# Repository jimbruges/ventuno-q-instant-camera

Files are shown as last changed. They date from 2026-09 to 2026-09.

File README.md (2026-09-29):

# VENTUNO Q Instant Camera

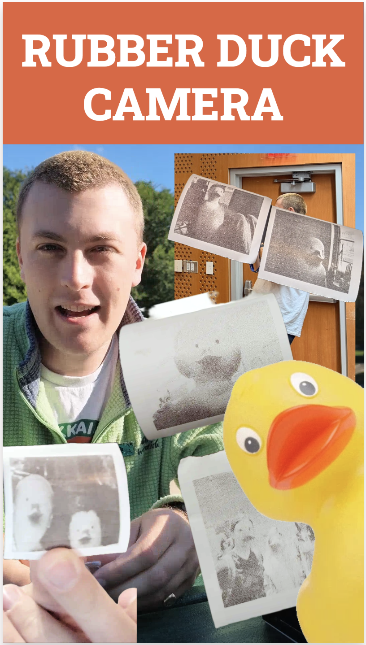
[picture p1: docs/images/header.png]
VENTUNO Q Rubber Duck Camera


A headless instant-camera photobooth for the Arduino VENTUNO Q. It combines a USB webcam, Modulino Buttons and Pixels, the onboard LED matrix, a serial thermal printer, local VLM descriptions, and optional local NPU or cloud image editing.

> [Watch the build video on YouTube](https://www.youtube.com/shorts/uCNsJqf2ZmI)

## Start here

1. Read the [hardware build guide](hardware/README.md) to print the case, assemble the camera, and wire the printer safely.
2. Run [`./install.sh`](#install-on-a-ventuno-q) on a VENTUNO Q to install the application and optional local image-editing bundle.
3. Open the browser interface at `http://<board-ip>:7000` to configure the button profiles and make a test print.

The camera can run completely headless once it has been configured. Use the three Modulino Buttons as the shutter controls, while the Modulino Pixels and the VENTUNO Q LED matrix provide flash and status feedback.

## What it does

| Mode | Result |
| --- | --- |
| Normal | Captures the webcam image and prints it as a 384-dot monochrome receipt. |
| Local | Uses the VENTUNO Q NPU to edit the image locally. The default prompt replaces people's heads with rubber ducks. |
| Cloud | Sends an image-edit request through OpenRouter; this mode requires an API key and network access. |
| Describe | Uses the built-in local VLM to describe the scene and prints the text instead of a photo. |

- Six independently configurable profiles: a short press and a long press for each of the three buttons.
- A browser UI on port 7000 for configuration, live previews, test prints, and recent-print history.
- Screenless Android Wi-Fi setup by scanning a Wi-Fi sharing QR code with the webcam.
- Local image editing through QNN/HTP contexts compiled for the VENTUNO Q QCS8275.

## Hardware

- Arduino VENTUNO Q with a current App Lab image and `arduino-app-cli`.
- UVC USB webcam.
- Modulino Buttons and Modulino Pixels connected over Qwiic/I2C.
- TTL thermal printer on D1/TX at 9600 baud, powered by the dedicated 9 V output of the USB-C PD trigger and sharing ground with the VENTUNO Q.

See the [hardware build guide](hardware/README.md) for assembly and wiring, and [the app README](ArduinoApps/instant-me-camera/README.md) for controls and operation.

### Bill of materials

| Component | Quantity |
| --- | ---: |
| [USB C PD 9V trigger adapter](https://m.media-amazon.com/images/I/71KljqwlDBL._AC_SX679_.jpg) | 1 |
| USB-C panel-mount extension cable | 1 |
| Anker USB-C power bank | 1 |
| [Modulino Buttons](https://cdn.shopify.com/s/files/1/0438/4735/2471/files/ABX00110_01.iso.jpg?v=1747144627) | 1 |
| [Snap-in spacers for Modulino boards and VENTUNO Q](https://media.rs-online.com/image/upload/bo_1.5px_solid_white,b_auto,c_pad,dpr_2,f_auto,h_399,q_auto,w_710/c_pad,h_399,w_710/F0304193-01?pgw=1) | 14 |
| [CSN-A2 58mm thermal printer](https://thepihut.com/cdn/shop/files/mini-thermal-receipt-printer-the-pi-hut-105116-40741308137667_1000x.jpg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) | 1 |
| [Modulino Pixels](https://cdn.shopify.com/s/files/1/0438/4735/2471/files/ABX00109_01.iso.jpg?v=1747144631) | 1 |
| M3 x 5 mm heat-set inserts | 4 |
| [Logitech C270 webcam](https://m.media-amazon.com/images/I/61yo4swj-PL._AC_SX679_.jpg) | 1 |
| [40 colored male-to-male jumper wires](https://cdn.shopify.com/s/files/1/0438/4735/2471/files/TPX00160_00.default_6a832518-bf2a-406c-a2d1-a554b9949905.jpg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) | 1 pack |
| 15 cm solid-core hookup wires | 2 |
| [Arduino VENTUNO Q](https://cdn.shopify.com/s/files/1/0438/4735/2471/files/ABX00181_01.iso.jpg?v=1784300672) | 1 |
| M3 x 5 mm caphead screws | 4 |
| [Qwiic cable bundle](https://cdn.shopify.com/s/files/1/0438/4735/2471/files/TPX00232_01.iso.jpg?v=1755589661) | 1 bundle |

## 3D-printed enclosure

The enclosure is a three-part print sized around the VENTUNO Q, webcam, thermal printer, and Modulino boards: a top shell with the carry handle and camera/button cutouts, a bottom shell with a printer bay, and a vented side panel for airflow around the board.

| Front cutouts | Vented side panel | Interior shell |
| --- | --- | --- |
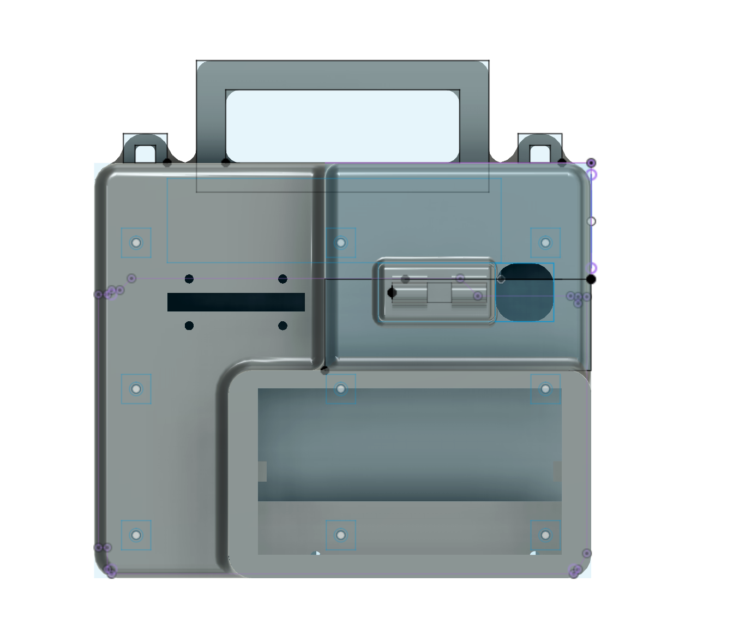
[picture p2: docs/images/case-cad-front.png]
Front panel with lens, button, and printer cutouts
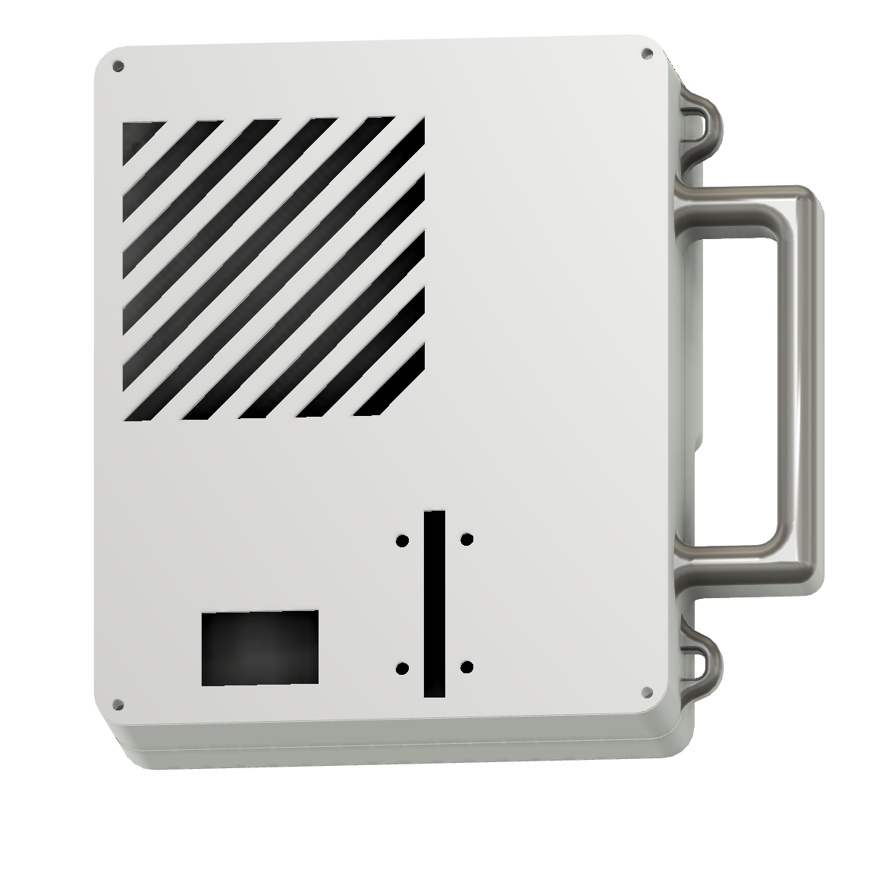
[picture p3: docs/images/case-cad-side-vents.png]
Side panel with ventilation slots and carry handle
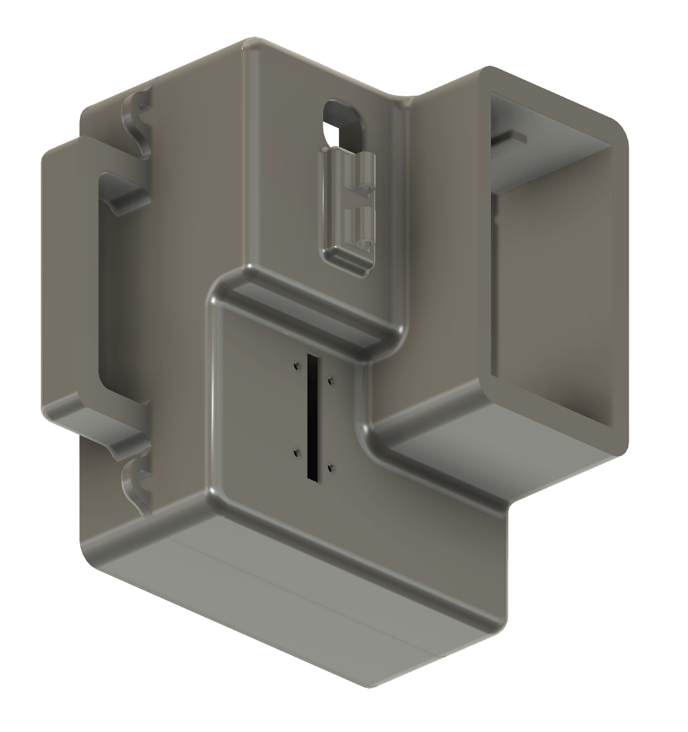
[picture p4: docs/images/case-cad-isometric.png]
Interior view of the printed shell
|  |  |  |

Use this layout for printing; supports are required for the front plate:

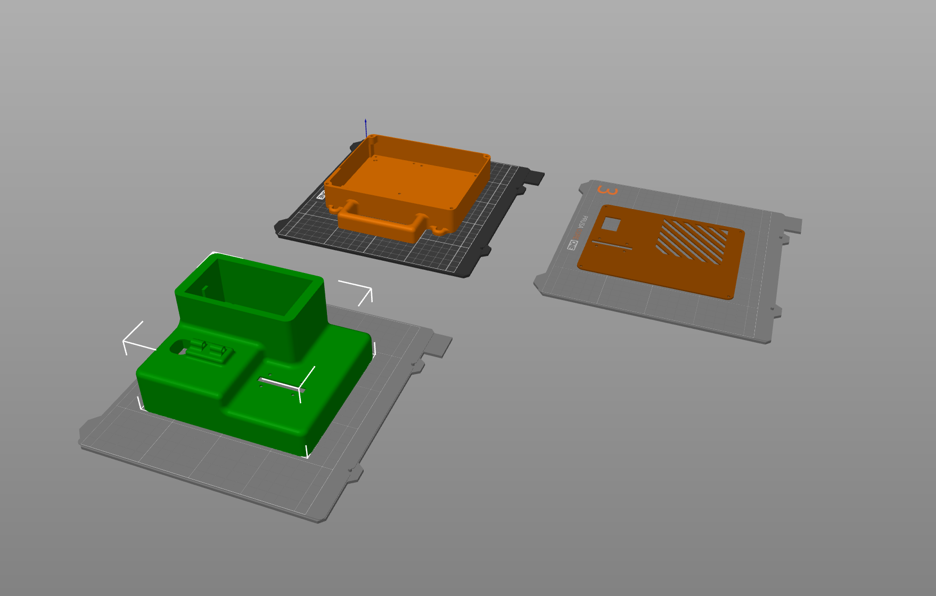
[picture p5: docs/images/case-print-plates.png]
Slicer plate layout for the lid, body, and side panel


Download the [3MF enclosure file](hardware/ventuno-q-instant-camera.3mf) for all three parts. See the [hardware build guide](hardware/README.md) for the assembly sequence.

Tested on a Prusa Core One+.

## Install on a VENTUNO Q

The installer is intended to run on the VENTUNO Q. It downloads about 3.1 GB of
compressed NPU runtime/model artifacts from Hugging Face, installs roughly 6 GB,
and needs at least 8 GB free during installation. Model downloads are public and
do not require a Hugging Face account.

```bash
git clone https://github.com/jimbruges/ventuno-q-instant-camera.git
cd ventuno-q-instant-camera
./install.sh
```

The installer:

1. Verifies that it is running on a VENTUNO Q.
2. Copies the Arduino App to `~/ArduinoApps/instant-me-camera`.
3. Downloads and checksum-verifies the pinned Hugging Face `v1` model bundle.
4. Installs the portable NPU and Wi-Fi user services.
5. Enables both services, sets the app as the boot default, and starts it.

Then open `http://<board-ip>:7000`. The first NPU startup may take up to two minutes.

Useful alternatives:

```bash
./install.sh --skip-models   # Normal, Cloud, and Describe modes only
./install.sh --no-start      # Install without starting or changing the default app
./scripts/install-models.sh  # Install/reinstall only the local NPU bundle
```

The installer preserves runtime `config.json`, `.secrets.json`, captures, and profile photos on upgrades.

> **Want the fastest first print?** Run `./install.sh --skip-models` to install Normal, Cloud, and Describe modes without the multi-gigabyte local editor. You can add Local mode later with `./scripts/install-models.sh`.

## Configuration

The app works without `config.json`; defaults are portable and discover the Docker host gateway automatically. To customize settings manually:

```bash
cp ~/ArduinoApps/instant-me-camera/config.example.json \
   ~/ArduinoApps/instant-me-camera/config.json
```

Cloud mode needs an OpenRouter API key entered in the Web UI. It is stored in the ignored, owner-only `.secrets.json` file and is never committed.

## Models and large files

Model files are not stored in Git history. The supported bundle is distributed
as checksummed artifacts from a dedicated Hugging Face model repository. This
keeps source clones small while pinning the exact ARM64 runtime and QCS8275
contexts.

See [MODELS.md](MODELS.md) for artifact contents, upstream model licenses, and installation details.

## License

Original source code, documentation, and enclosure CAD files in this repository
are available under the [Mozilla Public License 2.0](LICENSE), unless a file or
directory includes a different notice. Third-party libraries, model artifacts,
reference images, product images linked from the bill of materials, Arduino and
Qualcomm components, and the trademarks shown in this project remain subject to
their respective licenses and terms. See [MODELS.md](MODELS.md) and
[huggingface/README.md](huggingface/README.md) for the local model licensing and
provenance details.

## Repository layout

- `ArduinoApps/instant-me-camera/`: App Lab application, MCU sketch, Web UI, and Wi-Fi helper.
- `instant-camera-ai/src/`: local QNN inference pipeline.
- `instant-camera-ai/bin/start-npu-router`: portable NPU service launcher.
- `instant-camera-ai/systemd/`: user service template.
- `scripts/install-models.sh`: release artifact downloader and verifier.
- `install.sh`: complete board installer.
- `hardware/`: 3D-printable enclosure source (`.3mf`) and build instructions.
- `docs/images/`: README screenshots and renders.

## Operations

```bash
systemctl --user status instant-camera-npu.service
systemctl --user status instant-camera-wifi.service
curl http://127.0.0.1:7100/health
arduino-app-cli app logs ~/ArduinoApps/instant-me-camera --tail 100
arduino-app-cli app start ~/ArduinoApps/instant-me-camera
```

Only one Arduino App can run at a time. Starting this app stops the currently running app.

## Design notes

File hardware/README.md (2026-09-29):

# Hardware build

This folder contains the [VENTUNO Q Instant Camera enclosure](ventuno-q-instant-camera.3mf). The enclosure is a three-part print for the VENTUNO Q, Logitech C270 webcam, CSN-A2 58 mm thermal printer, Modulino Buttons, and Modulino Pixels.

## Parts

- Arduino VENTUNO Q
- Logitech C270
- Modulino Buttons
- Modulino Pixels
- Snap-in spacers for Modulino boards and VENTUNO Q, 14
- CSN-A2 58 mm thermal printer
- USB-C PD 9 V trigger adapter and a compatible USB-C PD power source
- USB-C panel-mount extension cable, 1
- Anker USB-C power bank, 1
- Qwiic cables for the Modulino peripherals
- M3 x 5 mm heat-set inserts, 4
- M3 x 5 mm caphead screws, 4
- 15 cm solid-core hookup wires, 2
- Male-to-male jumper wires for the printer serial connection and other signal connections

The complete bill of materials, including product references, is in the [main README](../README.md#bill-of-materials).

## Print the enclosure

1. Open `ventuno-q-instant-camera.3mf` in the slicer.
2. Keep the three enclosure parts on their intended plates and confirm the printer profile matches the selected material.
3. Use supports for the front plate. Check the camera mount, button, and printer openings after slicing.
4. Print the parts and remove support material before installing electronics.
5. Test-fit the VENTUNO Q, printer, webcam, and Modulino parts before tightening the enclosure screws.

The model was tested on a Prusa Core One+. The `.3mf` contains the printable enclosure source; it does not include the electronics or fasteners.

## Install the heat-set inserts

Install four M3 x 5 mm inserts in the enclosure's prepared mounting holes:

1. Heat a soldering iron to the insert manufacturer's recommended temperature.
2. Place each insert squarely over its printed hole.
3. Press it in slowly until it is flush with the plastic surface. Do not force it below the mounting surface.
4. Let the plastic cool completely, then test each thread with an M3 screw.

Keep the insert aligned while it is hot. Misaligned inserts can prevent the shells from closing or damage the printed mounting bosses.

## Mount the components

Before committing the electronics to the enclosure, connect the VENTUNO Q, Modulino boards, thermal printer, and camera on the bench and confirm that the App starts and the camera is visible.

### Front plate

1. Remove the C270 factory mounting clip by popping off the hinge end cap and removing the screw. Reattach the clip to the front plate; its keyed shaft fits in one direction. Feed the USB cable through the enclosure opening before securing the camera.
2. Feed the printer cables through the printer opening. Use double-sided tape on the printer body to hold the printer in position, keeping the paper path aligned with the front slot.
3. Fit the snap-in spacers and attach the Modulino Pixels to the front plate. Feed a long Qwiic cable through from the Pixels board.
4. Set the USB-C PD screw-terminal adapter to its switched 9 V mode. Connect its output to the printer power terminals, then add the two 15 cm solid-core wires for the VENTUNO Q power input.
5. Secure the panel-mount USB-C extension in the enclosure and connect its internal end to the USB-C PD screw-terminal adapter.

### Middle and rear panels

1. Feed all loose cables through the panel gap before fastening the middle mounting panel to the front plate.
2. Connect the printer RX input to VENTUNO Q D1 / TX with a jumper wire. The current sketch only sends print data; leave printer TX disconnected unless it is level-shifted to 3.3 V before connecting to D0 / RX.
3. Connect the USB camera and route its cable clear of the printer and paper path.
4. Connect the two printer power leads to the VENTUNO Q screw terminals marked 5-24 V and GND. The printer and VENTUNO Q must share ground.
5. Fit the snap-in spacers for the Modulino Buttons on the outer side of the rear panel and attach the board.
6. Test-fit the VENTUNO Q in its opening before pressing in its snap-in spacers. The fit can be tight; confirm alignment before committing the spacers.
7. Connect a Qwiic cable from the VENTUNO Q to the Modulino Buttons, then connect the Modulino Pixels to the Buttons board.
8. Check every connector and cable, then fasten the rear panel.
9. Place the Anker power bank in its slot with the built-in USB-C cable un-stowed and the cable end facing outward.
10. Load a paper roll in the thermal printer according to the printer manual.
11. Connect the power bank to the panel-mount USB-C socket and power up the board.

Do not trap cables between the shells. Leave enough slack to remove the top shell without pulling on the Qwiic connectors or printer terminals.

## Wiring

### Modulino peripherals

Connect Modulino Buttons and Modulino Pixels to the VENTUNO Q over Qwiic/I²C. The sketch initializes the Modulino bus on `Wire1`, then polls the three buttons and drives the eight Modulino Pixels.

- Use Qwiic cables between the VENTUNO Q and the Modulino peripherals.
- Keep the connectors fully seated and avoid sharply bending the Qwiic cables at the enclosure edge.
- The three buttons are treated as A, B, and C from left to right in the app controls.

### Webcam

Connect the Logitech C270 to a VENTUNO Q USB host port. The default camera setting is `auto`; this selects the stable USB capture interface and avoids relying on changing `/dev/video*` numbers. The webcam must be visible to the Linux side before starting the App.

### Thermal printer

The printer uses the VENTUNO Q `Serial1` interface at 9600 baud, 8-N-1:

| Printer connection | VENTUNO Q / power connection |
| --- | --- |
| RX | D1 / TX |
| GND | VENTUNO Q GND and external supply GND |
| Power | Separate regulated 5-9 V supply rated for at least 1.5 A |
| TX | Leave disconnected |

The VENTUNO Q sends print data to the printer and does not currently read printer status. If printer TX is connected in a future revision, level-shift its 5 V signal to 3.3 V before connecting it to D0 / RX.

**Do not power the printer from the VENTUNO Q 3.3 V or 5 V logic header.** The printer's motor and print head can draw more current than those rails provide. Verify the external supply voltage and polarity before connecting it, and always share ground with the VENTUNO Q.

### USB-C PD trigger

Use the USB-C PD trigger adapter only with a compatible USB-C PD source and only after confirming its negotiated output. Set the adapter for the voltage required by the printer power input, within the printer's rated 5-9 V range. Do not connect an unverified PD output to the VENTUNO Q or printer.

## First bring-up

1. Load paper and verify that the paper exits through the front slot.
2. Leave the printer TX disconnected and connect the printer's external supply and shared ground.
3. Connect the webcam and Qwiic peripherals.
4. Install the App with `./install.sh`, or start the App from App Lab.
5. Open the Web UI and run **Test Print** before enabling print-after-capture.
6. Check the App logs and MCU monitor if the printer or peripherals do not respond.

The full software installation and operating instructions are in [the main README](../README.md) and [the app README](../ArduinoApps/instant-me-camera/README.md).

## Physical controls

- Short press A, B, or C runs that button's short profile.
- Hold a button for at least 900 ms to run its long profile.
- Press any button while a capture, generation, print, or Wi-Fi operation is active to cancel it.
- Hold A and C together for 1.5 seconds while Ready to start screenless Wi-Fi QR setup.
- The Modulino Pixels provide the capture flash and status lighting; the VENTUNO Q LED matrix shows camera and printer states.

The default profiles are A short Normal, B short Cloud, C short Local, A long Describe, B long Cloud, and C long Local. Cloud mode needs an OpenRouter key and network access; Local mode needs the Standard NPU bundle installed and healthy; Describe mode uses the local VLM Brick.

## Safety checklist

Before closing the enclosure, confirm:

- The printer has a separate regulated supply rated for its load.
- Printer ground and VENTUNO Q ground are connected.
- Printer TX is disconnected.
- No exposed conductor can contact the printer frame or enclosure hardware.
- Wires cannot enter the paper path or touch the hot print head.
- The webcam has a clear view through the front opening.
- The M3 inserts are flush and the caphead screws do not bind.

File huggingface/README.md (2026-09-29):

---
license: creativeml-openrail-m
library_name: onnxruntime
pipeline_tag: image-to-image
tags:
  - arduino
  - ventuno-q
  - qnn
  - qualcomm
  - stable-diffusion
  - instruct-pix2pix
  - ip-adapter
---

# VENTUNO Q Instant Camera Models

Compiled local image-editing runtime for the [VENTUNO Q Instant Camera](https://github.com/jimbruges/ventuno-q-instant-camera).

This repository contains checksummed ARM64 Python runtime archives and Qualcomm QNN context binaries for the Arduino VENTUNO Q. The contexts are compiled for the target Qualcomm QCS8275 / HTP v75 profile and are not portable to unrelated hardware.

## Install

From a clone of the source repository, run:

```bash
./scripts/install-models.sh
```

The installer pins the immutable `v1` tag, downloads one archive at a time, verifies `SHA256SUMS`, and extracts into `~/instant-camera-ai`.

## Contents

- Stable Diffusion 1.5 text encoder and VAE QNN contexts.
- InstructPix2Pix VAE encoder context.
- IP-Adapter Plus reference encoder and editor U-Net contexts.
- Stable Diffusion 1.5 CLIP tokenizer.
- ARM64 ONNX Runtime QNN Python environment.
- Upstream license texts and build provenance.

The complete experimental model tree is intentionally excluded. This repository contains only the components required by the supported `standard` local editor.

## Licensing

The compiled contexts are modified forms of upstream model components:

- Stable Diffusion 1.5: CreativeML OpenRAIL-M.
- InstructPix2Pix: MIT, with Stable Diffusion restrictions applying to derived model weights.
- IP-Adapter: Apache-2.0.
- ONNX Runtime QNN and its bundled Python dependencies retain their included licenses.

The model-license archive is installed under `~/instant-camera-ai/model-licenses`. Use of these artifacts is subject to CreativeML OpenRAIL-M, including its use restrictions. This repository is not affiliated with or endorsed by Arduino, Qualcomm, Stability AI, RunwayML, Timothy Brooks, or Tencent AI Lab.

## Provenance

The QNN contexts were compiled through Qualcomm AI Hub for the `Arduino VENTUNO Q` target. See `PROVENANCE.txt` in the license archive for component details. Checksums cover the exact downloadable archives; immutable repository tags identify published bundle versions.

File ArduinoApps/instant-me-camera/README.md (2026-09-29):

# VENTUNO Q AI Camera

An App Lab instant camera and thermal-printing photobooth for VENTUNO Q. It can run headless from Modulino Buttons while the Web UI provides configuration, test captures, test prints, and recent-print history.

## Headless controls

- Buttons A, B, and C each have independently configurable short-press and long-press profiles.
- Every profile can run Normal, Local, Cloud, or Describe mode. Describe sends the captured webcam scene to the built-in local VLM and prints its text description instead of an image.
- A press held for at least 900 ms selects the long-press profile; a shorter press selects the short-press profile.
- Press any Modulino button while capture, generation, printing, or Wi-Fi setup is active to cancel the process and return to Ready. The Web UI shutter performs the same action while a process is active.

Button A long press uses Describe by default. It runs locally through the `arduino:vlm` Brick and its configured `genie:qwen3_vl_4b_instruct` model; it does not require a cloud API key.

A button LED is steady when either of its profiles is available. Cloud profiles require their own reference image, an OpenRouter API key, and internet access. Local profiles require their selected NPU model to be ready. The selected button flashes while a job runs. The LED matrix shows ready, capture, processing/printing, success, and error states; Modulino Pixels provide the shutter flash.

The Web UI is optional during operation. Select one of the six profile tiles, configure it, and apply its settings; profiles and reference images persist across app and board restarts. With `camera` set to `auto`, the app selects the USB webcam's stable index-0 capture interface and ignores Qualcomm camera control/codec nodes whose `/dev/video*` numbers may change between boots.

## Screenless Wi-Fi setup

Hold Modulino Buttons A and C together for 1.5 seconds while the camera is ready. The LED matrix changes to a scanning frame and the Modulino Pixels illuminate the QR code. Show the webcam an Android Wi-Fi sharing QR code (`WIFI:...`) within two minutes. Press any button again to cancel scanning. The matrix shows connection progress, a checkmark on success, or an X on failure, and returns to the normal ready display automatically.

Wi-Fi setup supports open, WEP, WPA/WPA2, and WPA3/SAE sharing codes, including hidden networks. Network credentials are sent over an owner-only Unix socket to a host user service and are not written to the application configuration. After a successful scan, the thermal printer prints the decoded SSID and PSK, followed by a second ticket containing the connection result or failure message. The PSK is not written to application logs. The helper is installed on this board as `instant-camera-wifi.service`. To install it after copying the App to another board:

```bash
mkdir -p ~/.config/systemd/user
cp ~/ArduinoApps/instant-me-camera/tools/instant-camera-wifi.service ~/.config/systemd/user/
systemctl --user daemon-reload
systemctl --user enable --now instant-camera-wifi.service
```

The scan timeout defaults to 120 seconds and can be overridden with `WIFI_SCAN_TIMEOUT` in App configuration.

## Startup

`VENTUNO Q AI Camera` is configured as the App CLI default and starts automatically when the board boots. The local Standard NPU model is managed by the enabled `instant-camera-npu.service` user service in `~/.config/systemd/user/`; user lingering keeps that service active without an interactive login. The Web UI's confirmed **Shut Down Application** action stops the App Lab application, its App-managed Genie model, the NPU image service, and its Wi-Fi and model-control helpers. The Web UI disconnects when shutdown completes; restart the application and helpers from App Lab or rerun the installer.

## Thermal printer wiring

The printer is driven at 9600 baud (8-N-1) through `Serial1`:

- VENTUNO Q D1 / TX to printer RX.
- VENTUNO Q GND to printer GND.
- Printer power to a separate regulated 5-9 V supply rated for at least 1.5 A.
- Keep printer TX disconnected. If status receive is added later, level-shift it from 5 V to 3.3 V before connecting to VENTUNO Q D0 / RX.

For the enclosure build, the printer is powered from the USB-C PD trigger's switched 9 V output. The trigger is fed through the panel-mount USB-C cable from the Anker power bank; its second output pair supplies the VENTUNO Q 5-24 V and GND screw terminals.

Never power the printer from the board's 3.3 V or 5 V logic header. The external supply and VENTUNO Q must share ground. Start with the default heat and density values; overly aggressive settings increase current demand and can overheat the print head.

The Linux app converts each result to a 384-dot, one-bit raster and sends up to eight rows per acknowledged Bridge call. A rejected transfer is cancelled on the MCU so later print jobs are not blocked.

## Bring-up

1. Power the printer externally with paper loaded, common ground connected, and printer TX disconnected.
2. Start the App from App Lab. This uploads the MCU sketch and stops any currently running App.
3. Check the App logs for Python startup errors and the MCU monitor for sketch output.
4. Use **Test Print** in the Web UI before enabling print-after-capture.
5. Trigger A, then C, then B after configuring `OPENROUTER_API_KEY` in Brick Configuration.

A real test print requires the physical wiring above.

## Image modes

- `normal`: prints the captured image without AI editing.
- `local`: the default rubber-duck effect, using FP16 InstructPix2Pix and IP-Adapter Plus on the VENTUNO Q HTP/NPU. It accepts a captured image, an optional reference image, and a flexible instruction.
- `cloud`: OpenRouter's image editing API. Set its API key in Cloud settings in the Web UI, or provide `OPENROUTER_API_KEY` through App Lab Brick Configuration.
- `describe`: sends the captured image to the local VLM and prints a short description instead of an image.

Copy `config.example.json` to `config.json` to override defaults. `config.json` is optional. Settings include the NPU and cloud prompts, OpenRouter model, camera brightness/contrast, print enable, raster threshold, paper feed, heat dots/time/interval, density, and break time. A key entered in the Web UI is stored separately in ignored `.secrets.json` with owner-only permissions and is never returned to the browser; a blank key field preserves it.

The web interface exposes all four capture modes, the NPU instruction and optional `object.jpg` reference, the cloud composition prompt and model, camera processing, printer controls, a diagnostic print, and reprints from recent history. Applied values take effect on the next exposure and are persisted to `config.json` for future app and board restarts. Source resolution controls preprocessing detail; the compiled editor graph always executes at 512x512.

The local model files are intentionally outside the App directory under `~/instant-camera-ai` so App Lab does not package several gigabytes of weights.

## Installed local stack

- `~/instant-camera-ai/src/instruct_pix2pix_generate.py`: NumPy InstructPix2Pix pipeline using ONNX Runtime QNN.
- `~/instant-camera-ai/src/npu_server.py`: persistent HTTP service exposing the `/edit` image-and-instruction endpoint.
- `~/instant-camera-ai/qnn-runtime`: ONNX Runtime 1.24.4 and `onnxruntime-qnn` 2.1.1, which bundles QNN 2.45.41.
- `~/instant-camera-ai/qnn-runtime-deps`: user-local `libatomic.so.1` and the `libcdsprpc.so` compatibility linker name required by the HTP v75 stub.
- `~/instant-camera-ai/models/qcs8275-sd15`: Qualcomm's precompiled QCS8275 Stable Diffusion 1.5 model contexts.
- `~/instant-camera-ai/models/qcs8275-instruct-pix2pix`: custom FP16 QNN VAE encoder and eight-channel editor U-Net contexts.
- `~/instant-camera-ai/models/qcs8275-ip-adapter-plus`: custom FP16 QNN CLIP Vision reference encoder and IP-Adapter-aware editor U-Net contexts.
- `tools/ffmpeg`: bundled static ARM64 webcam capture binary.

The NPU editor uses 20 Euler ancestral steps with separate text and image guidance. A verified 512x512 edit completed in 25.2 seconds. Warm component timings were 310 ms for source encoding and about 400 ms for each editor U-Net pass; each step performs three U-Net passes.

The local image backend uses Qualcomm's dedicated QNN Stable Diffusion contexts and `/dev/fastrpc-cdsp` directly through ONNX Runtime QNN.

Preprocessing preserves the webcam frame's native aspect ratio without padding, borders, or destructive center crops. Captures are not rotated by default; set `camera_rotation` to `90`, `-90`, or `180` only if the camera is mounted differently.

OpenRouter support accepts either `message.images` or image items in the response content array.

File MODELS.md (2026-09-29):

# Local model installation

## Why models are release assets

The supported installation pins a minimal VENTUNO Q bundle to the immutable `v1`
tag of the public Hugging Face model repository
`jimbruges/ventuno-q-instant-camera-models`. `scripts/install-models.sh`
downloads one asset at a time, verifies it against `SHA256SUMS`, extracts it,
and deletes the archive before continuing.

The release also installs the applicable upstream licenses under
`~/instant-camera-ai/model-licenses`. Installing or using the bundle means you
must comply with those terms, including the Stable Diffusion use restrictions.

The installer expects these assets plus `SHA256SUMS`:

```text
runtime-qnn-aarch64.tar.zst
model-sd15-qcs8275.tar.zst
model-instruct-pix2pix-qcs8275.tar.zst
model-ip-adapter-reference-qcs8275.tar.zst
model-ip-adapter-unet-qcs8275.tar.zst
tokenizer-sd15.tar.zst
model-licenses.tar.zst
```

## Default NPU bundle

The default Local mode requires:

- An ARM64 Python runtime with ONNX Runtime and the QNN execution provider.
- Qualcomm QCS8275 Stable Diffusion 1.5 text encoder and VAE contexts.
- FP16 InstructPix2Pix VAE encoder context.
- FP16 IP-Adapter Plus reference encoder and editor U-Net contexts.
- A pinned Stable Diffusion 1.5 CLIP tokenizer for offline startup.

The NPU service runs with `HF_HUB_OFFLINE=1`; after installation it does not
download model or tokenizer files at startup.

Installed layout:

```text
~/instant-camera-ai/
├── bin/start-npu-router
├── src/
├── qnn-runtime/
└── models/
    ├── tokenizer/
    ├── qcs8275-sd15/
    ├── qcs8275-instruct-pix2pix/
    └── qcs8275-ip-adapter-plus/
```

The board firmware identifies the product as `arduino,monza`. Qualcomm tooling names
the compatible compiled-context target QCS8275/HTP v75; those directory names are
expected and do not indicate a board-detection mismatch. The contexts are not portable
to unrelated boards.

## Upstream models

The compiled pipeline derives from:

- Stable Diffusion 1.5: `stable-diffusion-v1-5/stable-diffusion-v1-5`, CreativeML OpenRAIL-M.
- InstructPix2Pix: `timbrooks/instruct-pix2pix`, MIT.
- IP-Adapter: `h94/IP-Adapter`, Apache-2.0.

Users remain responsible for complying with the upstream licenses and acceptable-use terms. The release contains compiled inference contexts, not the full source checkpoints.

## Install or verify

```bash
./scripts/install-models.sh
systemctl --user restart instant-camera-npu.service
curl http://127.0.0.1:7100/health
```

Override the repository or revision when testing a new bundle:

```bash
MODEL_REVISION=v2 ./scripts/install-models.sh
MODEL_REPO=another-user/another-model ./scripts/install-models.sh
```

`INSTANT_CAMERA_AI_HOME` overrides the default `~/instant-camera-ai` target for
manual model installs and launcher testing. The systemd unit intentionally uses
the canonical home-relative location installed by `install.sh`.

No Hugging Face account or CLI is required to install the public bundle; downloads
use HTTPS and `curl`.

Maintainers can assemble a replacement release directly from a prepared VENTUNO Q
without retaining duplicate archives:

```bash
MODEL_REVISION=v2 ./scripts/publish-hf-models.sh --publish
```

On a board with limited internal storage, point the one-at-a-time archive
workspace at a mounted USB drive:

```bash
MODEL_ARCHIVE_TMPDIR=/media/arduino/UNTITLED \
    MODEL_REVISION=v2 ./scripts/publish-hf-models.sh --publish
```

The publisher validates all inputs, embeds the upstream model licenses, uploads
one archive at a time, and creates the immutable revision tag only after all
checksums have been uploaded.

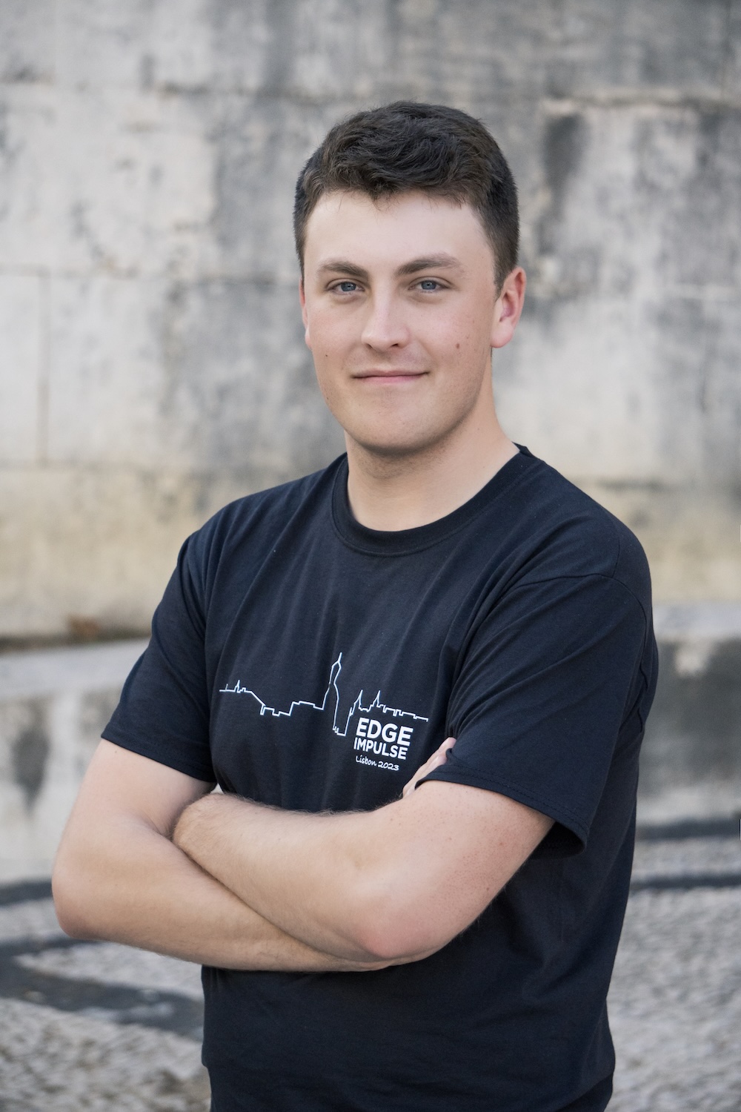
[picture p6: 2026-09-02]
ArduinoApps/instant-me-camera/assets/reference/me.jpg

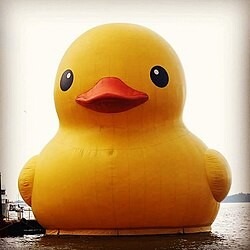
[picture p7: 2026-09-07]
ArduinoApps/instant-me-camera/assets/reference/object.jpg

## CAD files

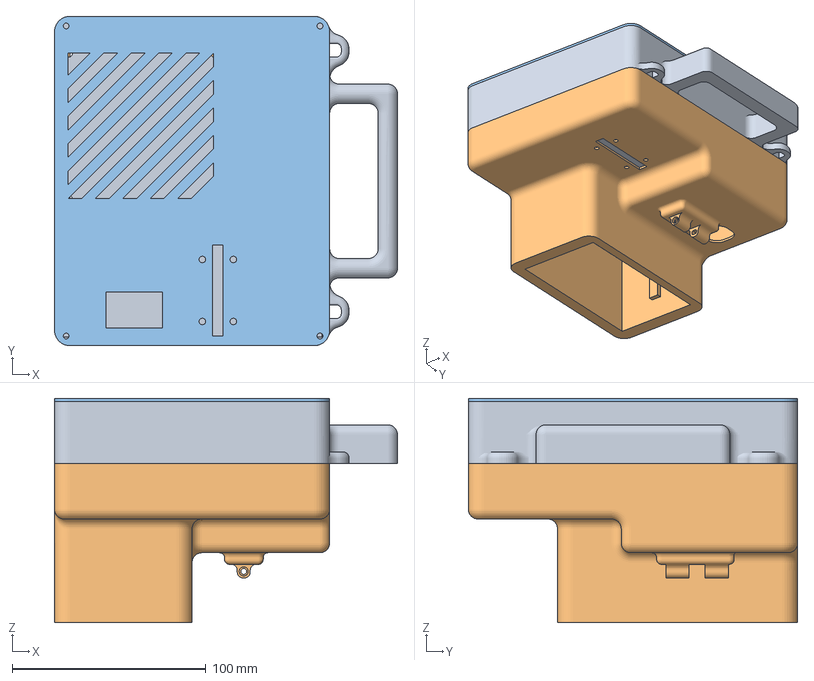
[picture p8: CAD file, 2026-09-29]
hardware/ventuno-q-instant-camera.3mf
177.0 x 170.0 x 115.6 mm
Board mount
Front Panel
Rear Panel

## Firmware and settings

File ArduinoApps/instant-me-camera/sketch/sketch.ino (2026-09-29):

#include <Adafruit_Thermal.h>
#include <Arduino_LED_Matrix.h>
#include <Arduino_Modulino.h>
#include <Arduino_RouterBridge.h>

Arduino_LED_Matrix matrix;
ModulinoButtons buttons;
ModulinoPixels pixels;
Adafruit_Thermal printer(&Serial1);

enum CameraState { READY, COUNTDOWN, CAPTURE, GENERATING, PRINTING, DONE, ERROR_STATE, WIFI_SCAN, WIFI_CONNECT, WIFI_SUCCESS, WIFI_ERROR };
CameraState cameraState = READY;
bool previousPressed[3] = {false, false, false};
bool optionsAvailable[6] = {false, false, false, false, false, false};
bool pressArmed[3] = {false, false, false};
unsigned long pressStartedAt[3] = {0, 0, 0};
bool wifiChordActive = false;
bool wifiChordTriggered = false;
unsigned long wifiChordStartedAt = 0;
bool printJobActive = false;
uint16_t printRowsExpected = 0;
uint16_t printRowsReceived = 0;
int8_t activeMode = -1;
unsigned long lastFrameAt = 0;
unsigned long captureFlashUntil = 0;
uint8_t animationFrame = 0;

void drawState();
void updateControls();
void updatePixels();
void setActiveMode(int mode);
void setOptions(int availabilityMask);
void setCameraStatus(String status);
bool setCaptureLight(bool enabled);
bool beginPrint(uint16_t rows);
bool appendPrintRows(std::vector<int> packedRows);
bool endPrint(uint8_t feedLines);
bool cancelPrint();
bool configurePrinter(uint8_t heatDots, uint8_t heatTime, uint8_t heatInterval, uint8_t density, uint8_t breakTime);
bool testPrint();
bool printWifiTicket(String title, String ssid, String psk, String message);

void setup() {
  matrix.begin();
  matrix.setGrayscaleBits(3);
  matrix.clear();
  Serial1.begin(9600);
  printer.begin();
  Bridge.begin();
  // provide_safe runs handlers in loop() context so they never race loop()'s I2C/matrix/printer access.
  Bridge.provide_safe("camera_status", setCameraStatus);
  Bridge.provide_safe("capture_light", setCaptureLight);
  Bridge.provide_safe("print_begin", beginPrint);
  Bridge.provide_safe("print_rows", appendPrintRows);
  Bridge.provide_safe("print_end", endPrint);
  Bridge.provide_safe("print_cancel", cancelPrint);
  Bridge.provide_safe("print_configure", configurePrinter);
  Bridge.provide_safe("print_test", testPrint);
  Bridge.provide_safe("print_wifi_ticket", printWifiTicket);
  Modulino.begin(Wire1);
  buttons.begin();
  pixels.begin();
  pixels.show();
  Bridge.provide_safe("set_active_mode", setActiveMode);
  Bridge.provide_safe("set_options", setOptions);
  drawState();
  updateControls();
}

void loop() {
  if (buttons.update()) {
    const char *profiles[6] = {
      "a_short", "b_short", "c_short",
      "a_long", "b_long", "c_long"
    };
    for (int index = 0; index < 3; index++) {
      bool pressed = buttons.isPressed(index) == HIGH;
      if (pressed && !previousPressed[index] && cameraState != READY) {
        printJobActive = false;
        printRowsExpected = 0;
        printRowsReceived = 0;
        captureFlashUntil = 0;
        cameraState = READY;
        activeMode = -1;
        drawState();
        updateControls();
        Bridge.notify("cancel_process");
      } else if (pressed && !previousPressed[index] && cameraState == READY) {
        pressArmed[index] = true;
        pressStartedAt[index] = millis();
      } else if (!pressed && previousPressed[index] && pressArmed[index] && cameraState == READY) {
        bool longPress = millis() - pressStartedAt[index] >= 900;
        int profileIndex = index + (longPress ? 3 : 0);
        if (optionsAvailable[profileIndex]) {
          Bridge.notify("take_photo", profiles[profileIndex]);
        }
        pressArmed[index] = false;
      } else if (!pressed) {
        pressArmed[index] = false;
      }
      previousPressed[index] = pressed;
    }
  }

  if (cameraState == READY && previousPressed[0] && previousPressed[2]) {
    if (!wifiChordActive) {
      wifiChordActive = true;
      wifiChordStartedAt = millis();
    } else if (!wifiChordTriggered && millis() - wifiChordStartedAt >= 1500) {
      wifiChordTriggered = true;
      pressArmed[0] = false;
      pressArmed[2] = false;
      Bridge.notify("wifi_setup");
    }
  } else {
    wifiChordActive = false;
    wifiChordTriggered = false;
  }

  if ((cameraState == COUNTDOWN || cameraState == GENERATING || cameraState == PRINTING || cameraState == WIFI_SCAN || cameraState == WIFI_CONNECT) && millis() - lastFrameAt > 160) {
    lastFrameAt = millis();
    animationFrame = (animationFrame + 1) % 8;
    drawState();
    updateControls();
  }
  if (captureFlashUntil && millis() >= captureFlashUntil) {
    captureFlashUntil = 0;
    updateControls();
  }
  delay(15);
}

void setOptions(int availabilityMask) {
  for (int index = 0; index < 6; index++) {
    optionsAvailable[index] = availabilityMask & (1 << index);
  }
  updateControls();
}

void setActiveMode(int mode) {
  activeMode = mode;
  updateControls();
}

void setCameraStatus(String status) {
  if (status == "ready") cameraState = READY;
  else if (status == "countdown") cameraState = COUNTDOWN;
  else if (status == "capture") cameraState = CAPTURE;
  else if (status == "generating") cameraState = GENERATING;
  else if (status == "printing") cameraState = PRINTING;
  else if (status == "done") cameraState = DONE;
  else if (status == "wifi_scan") cameraState = WIFI_SCAN;
  else if (status == "wifi_connect") cameraState = WIFI_CONNECT;
  else if (status == "wifi_success") cameraState = WIFI_SUCCESS;
  else if (status == "wifi_error") cameraState = WIFI_ERROR;
  else cameraState = ERROR_STATE;
  animationFrame = 0;
  drawState();
  updateControls();
}

bool setCaptureLight(bool enabled) {
  if (enabled) {
    for (int index = 0; index < 8; index++) pixels.set(index, WHITE, 100);
    pixels.show();
    captureFlashUntil = millis() + 20000;
  } else {
    captureFlashUntil = 0;
    updateControls();
  }
  return true;
}

bool beginPrint(uint16_t rows) {
  if (printJobActive || rows == 0 || rows > 2048) return false;
  printJobActive = true;
  printRowsExpected = rows;
  printRowsReceived = 0;
  cameraState = PRINTING;
  animationFrame = 0;
  drawState();
  updateControls();
  return true;
}

bool appendPrintRows(std::vector<int> packedRows) {
  constexpr size_t bytesPerRow = 48;
  constexpr size_t maxRowsPerChunk = 8;
  if (!printJobActive || packedRows.empty() || packedRows.size() % bytesPerRow != 0) return false;
  size_t rows = packedRows.size() / bytesPerRow;
  if (rows > maxRowsPerChunk || printRowsReceived + rows > printRowsExpected) return false;

  uint8_t bitmap[bytesPerRow * maxRowsPerChunk];
  for (size_t index = 0; index < packedRows.size(); index++) {
    if (packedRows[index] < 0 || packedRows[index] > 255) return false;
    bitmap[index] = static_cast<uint8_t>(packedRows[index]);
  }
  printer.printBitmap(384, rows, bitmap, false);
  printRowsReceived += rows;
  return true;
}

bool endPrint(uint8_t feedLines) {
  if (!printJobActive || printRowsReceived != printRowsExpected) return false;
  printer.feed(min(feedLines, static_cast<uint8_t>(8)));
  printJobActive = false;
  cameraState = DONE;
  drawState();
  updateControls();
  return true;
}

bool cancelPrint() {
  printJobActive = false;
  printRowsExpected = 0;
  printRowsReceived = 0;
  cameraState = ERROR_STATE;
  drawState();
  updateControls();
  return true;
}

bool configurePrinter(uint8_t heatDots, uint8_t heatTime, uint8_t heatInterval, uint8_t density, uint8_t breakTime) {
  if (printJobActive || heatDots < 1 || heatDots > 30 || heatTime < 3 || density > 20 || breakTime > 7) return false;
  printer.setHeatConfig(heatDots, heatTime, heatInterval);
  printer.setPrintDensity(breakTime, density);
  return true;
}

bool testPrint() {
  if (printJobActive) return false;
  cameraState = PRINTING;
  drawState();
  updateControls();
  printer.justify('C');
  printer.boldOn();
  printer.println("VENTUNO Q AI CAMERA");
  printer.boldOff();
  printer.println("Printer test OK");
  printer.feed(3);
  cameraState = DONE;
  drawState();
  updateControls();
  return true;
}

bool printWifiTicket(String title, String ssid, String psk, String message) {
  if (printJobActive) return false;
  printer.justify('C');
  printer.boldOn();
  printer.println(title);
  printer.boldOff();
  printer.justify('L');
  if (ssid.length()) {
    printer.print("SSID: ");
    printer.println(ssid);
  }
  if (psk.length()) {
    printer.print("PSK: ");
    printer.println(psk);
  }
  if (message.length()) printer.println(message);
  printer.feed(2);
  return true;
}

void updateControls() {
  if (cameraState == READY) {
    buttons.setLeds(
      optionsAvailable[0] || optionsAvailable[3],
      optionsAvailable[1] || optionsAvailable[4],
      optionsAvailable[2] || optionsAvailable[5]
    );
    updatePixels();
    return;
  }
  bool flashOn = animationFrame % 2 == 0;
  if (cameraState == WIFI_SCAN || cameraState == WIFI_CONNECT || cameraState == WIFI_SUCCESS || cameraState == WIFI_ERROR) {
    buttons.setLeds(flashOn, false, flashOn);
    updatePixels();
    return;
  }
  buttons.setLeds(
    activeMode == 0 && flashOn,
    activeMode == 1 && flashOn,
    activeMode == 2 && flashOn
  );
  updatePixels();
}

void updatePixels() {
  if (cameraState == CAPTURE && captureFlashUntil) return;
  pixels.clear();
  if (cameraState == WIFI_SCAN) {
    for (int index = 0; index < 8; index++) pixels.set(index, WHITE, 55);
  } else if (cameraState == WIFI_CONNECT) {
    pixels.set(animationFrame, 35, 190, 190, 35);
    pixels.set((animationFrame + 7) % 8, 20, 80, 80, 16);
  } else if (cameraState == WIFI_SUCCESS) {
    for (int index = 0; index < 8; index++) pixels.set(index, 35, 180, 95, 25);
  } else if (cameraState == WIFI_ERROR) {
    for (int index = 0; index < 8; index++) pixels.set(index, 220, 45, 35, 25);
  } else if (cameraState == COUNTDOWN || cameraState == GENERATING) {
    uint8_t red = activeMode == 2 ? 230 : 45;
    uint8_t green = activeMode == 0 ? 180 : (activeMode == 2 ? 155 : 125);
    uint8_t blue = activeMode == 1 ? 220 : 45;
    pixels.set(animationFrame, red, green, blue, 35);
  } else if (cameraState == PRINTING) {
    pixels.set(animationFrame, 35, 190, 190, 35);
    pixels.set((animationFrame + 7) % 8, 20, 80, 80, 16);
  } else if (cameraState == DONE) {
    for (int index = 0; index < 8; index++) pixels.set(index, 35, 180, 95, 25);
  } else if (cameraState == ERROR_STATE) {
    for (int index = 0; index < 8; index++) pixels.set(index, 220, 45, 35, 25);
  }
  pixels.show();
}

void drawState() {
  uint8_t frame[104] = {0};
  if (cameraState == READY) {
    for (int x = 3; x < 10; x++) { frame[2 * 13 + x] = 3; frame[6 * 13 + x] = 3; }
    for (int y = 2; y < 7; y++) { frame[y * 13 + 3] = 3; frame[y * 13 + 9] = 3; }
    frame[3 * 13 + 6] = 5; frame[4 * 13 + 5] = 5; frame[4 * 13 + 6] = 7;
    frame[4 * 13 + 7] = 5; frame[5 * 13 + 6] = 5;
  } else if (cameraState == WIFI_SCAN) {
    for (int x = 1; x < 5; x++) { frame[1 * 13 + x] = 4; frame[6 * 13 + x] = 4; }
    for (int x = 8; x < 12; x++) { frame[1 * 13 + x] = 4; frame[6 * 13 + x] = 4; }
    for (int y = 1; y < 4; y++) { frame[y * 13 + 1] = 4; frame[y * 13 + 11] = 4; }
    for (int y = 4; y < 7; y++) { frame[y * 13 + 1] = 4; frame[y * 13 + 11] = 4; }
    for (int x = 2; x < 11; x++) frame[animationFrame * 13 + x] = 7;
  } else if (cameraState == WIFI_CONNECT) {
    frame[7 * 13 + 6] = 7;
    if (animationFrame >= 2) { frame[5 * 13 + 5] = 5; frame[5 * 13 + 7] = 5; }
    if (animationFrame >= 4) { frame[3 * 13 + 3] = 4; frame[3 * 13 + 9] = 4; frame[4 * 13 + 4] = 4; frame[4 * 13 + 8] = 4; }
    if (animationFrame >= 6) { frame[1 * 13 + 1] = 3; frame[1 * 13 + 11] = 3; frame[2 * 13 + 2] = 3; frame[2 * 13 + 10] = 3; }
  } else if (cameraState == COUNTDOWN || cameraState == GENERATING || cameraState == PRINTING) {
    for (int x = 0; x < 13; x++) frame[animationFrame * 13 + x] = x == animationFrame ? 7 : 1;
  } else if (cameraState == CAPTURE) {
    for (int i = 0; i < 104; i++) frame[i] = 7;
  } else if (cameraState == DONE || cameraState == WIFI_SUCCESS) {
    for (int i = 0; i < 4; i++) frame[(4 + i) * 13 + (2 + i)] = 7;
    for (int i = 0; i < 5; i++) frame[(6 - i) * 13 + (6 + i)] = 7;
  } else if (cameraState == ERROR_STATE || cameraState == WIFI_ERROR) {
    for (int i = 1; i < 7; i++) { frame[i * 13 + i + 2] = 7; frame[i * 13 + 10 - i] = 7; }
  }
  matrix.draw(frame);
}

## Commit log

2026-09-02 Checkpoint QNN reference-guided camera
2026-09-07 fix: match thermal printer serial settings
    [sketch.ino]
2026-09-07 fix: stabilize selectable local image models
    [sketch.ino]
2026-09-14 feat: complete instant camera workflow
2026-09-14 Add button cancellation for active processes
2026-09-29 Add 3D-printed enclosure files and README hardware section
    [ventuno-q-instant-camera.3mf]
2026-09-29 Fix MCU hang by serializing Bridge handlers with loop()
    [sketch.ino]
